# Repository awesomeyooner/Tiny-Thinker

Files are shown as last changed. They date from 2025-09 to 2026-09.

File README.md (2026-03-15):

# Tiny-Thinker
Barebones STM32 board I made to learn PCB design. I took inspiration from [this tutorial](https://www.youtube.com/watch?v=aVUqaB0IMh4) as well as many other videos from PhilsLab, Robert Feranec, and many more!

## Resources

Instead of putting them here, I've put all my notes in this [repo!](https://github.com/awesomeyooner/KiCAD-Library/blob/main/docs/notes/Getting-Started.md)

I hope they're useful!

## Features

This is a 4-Layer PCB centered around the **STM32F446RCT6** (same as STM32F446RET6 but with less flash) with the following stackup:

- **L1** - SIGNAL (with GND Pour)
- **L2** - GND Plane
- **L3** - GND Plane
- **L4** - 3.3V PWR Plane + SIGNAL

Implemented Features:
- USB C FS (Device only)
- 5V Power Multiplexing (5V from USB + 5V from external source)
- User-toggleable LED
- PWR LED
- 2 2x20 Header pins for stackable expansion boards

This board breaks out the following:
- SPI1 and SPI2 (with CS)
- I2C1
- CAN1 (No Transciever)
- SWDIO
- USB_FS
- 8 x TIM Channels
- 4 x ADC Channels
- 4 x GPIO

## Pictures

### Schematic
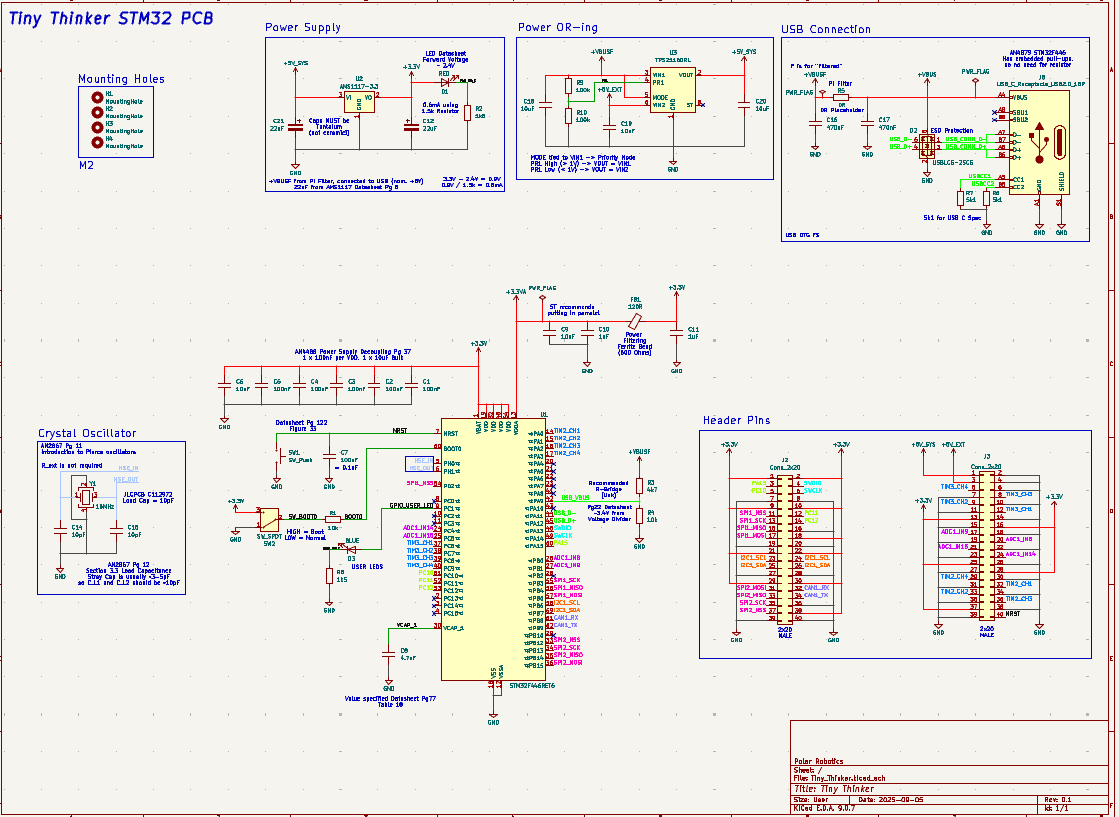
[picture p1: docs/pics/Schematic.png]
Schematic


### Layout and Routing
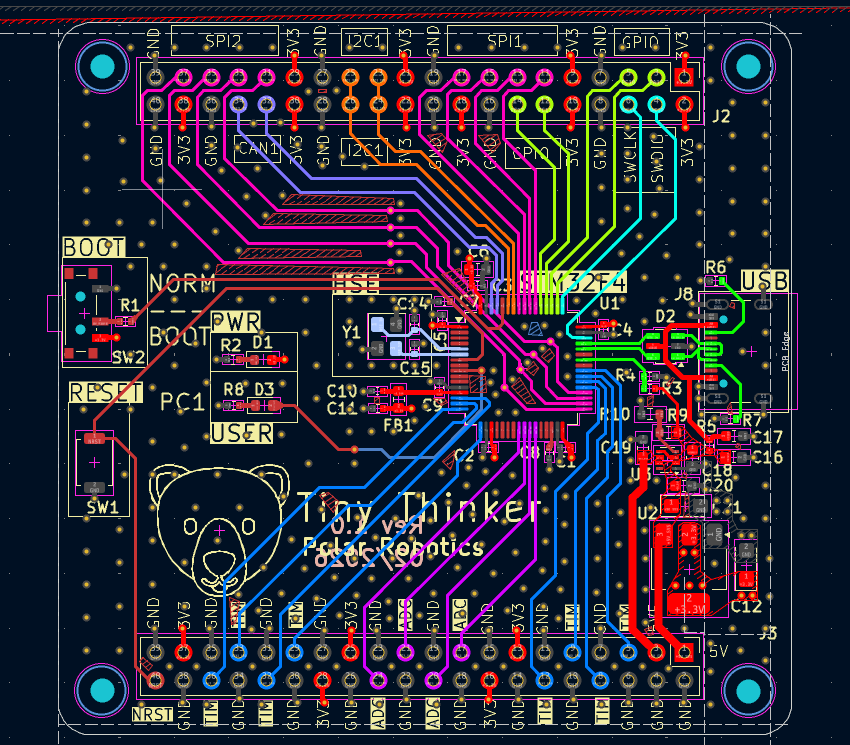
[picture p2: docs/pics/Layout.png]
Layout


### CAD
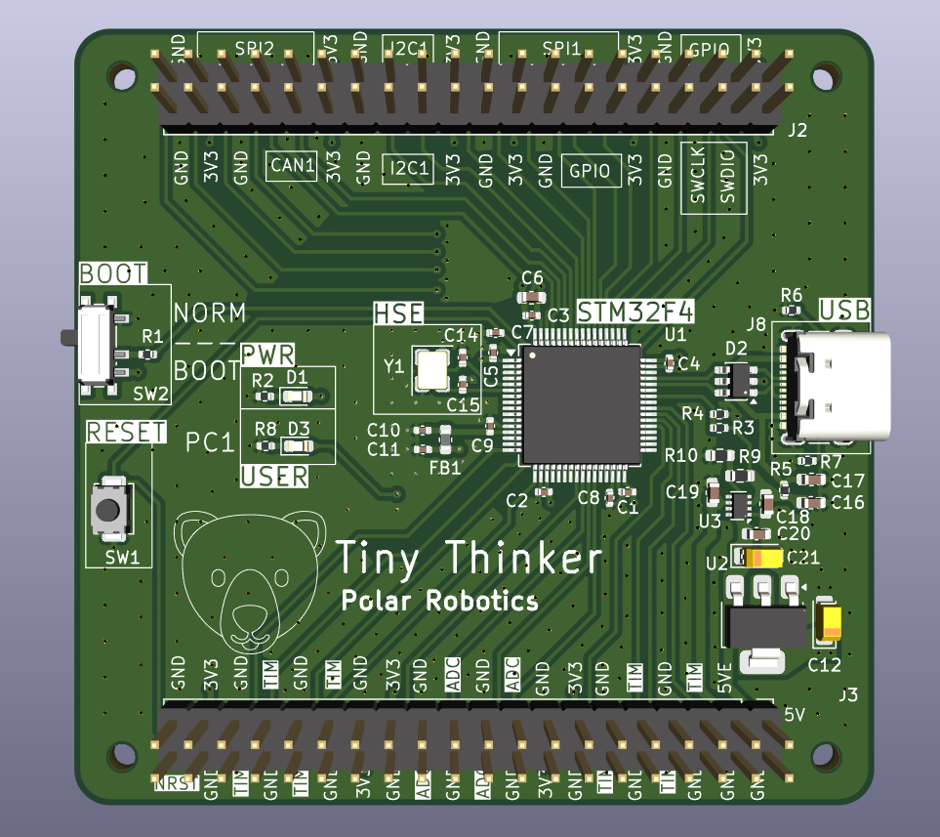
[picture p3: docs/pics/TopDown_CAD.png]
TopDown_CAD


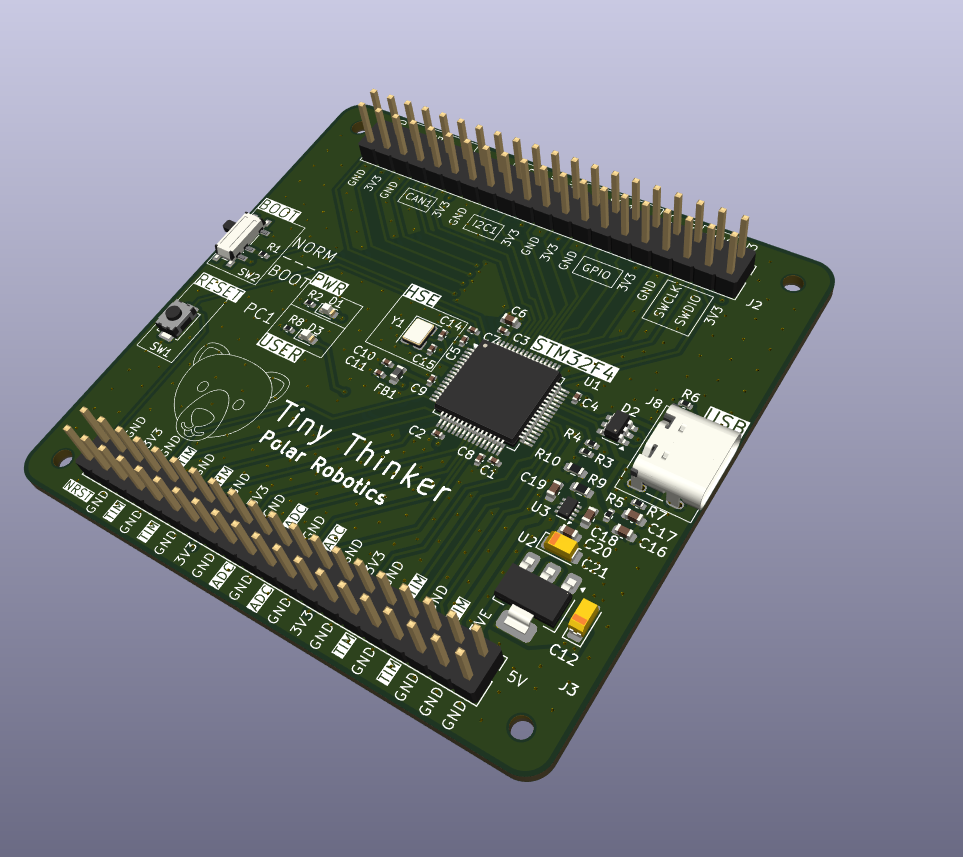
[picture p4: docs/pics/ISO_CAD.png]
ISO_CAD


### Assembled Product
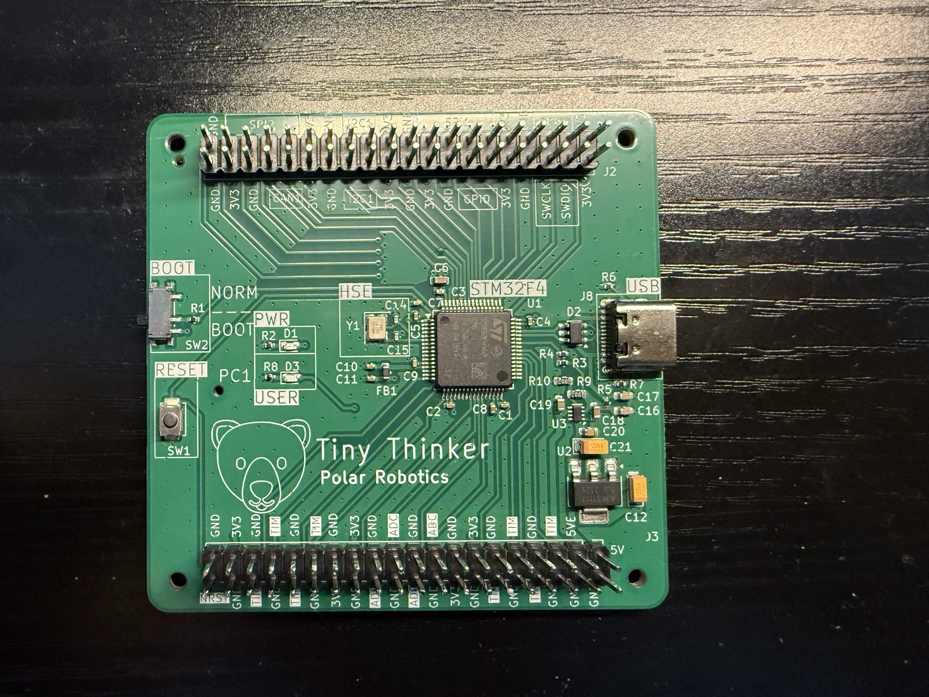
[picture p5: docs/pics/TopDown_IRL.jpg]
TopDown_IRL


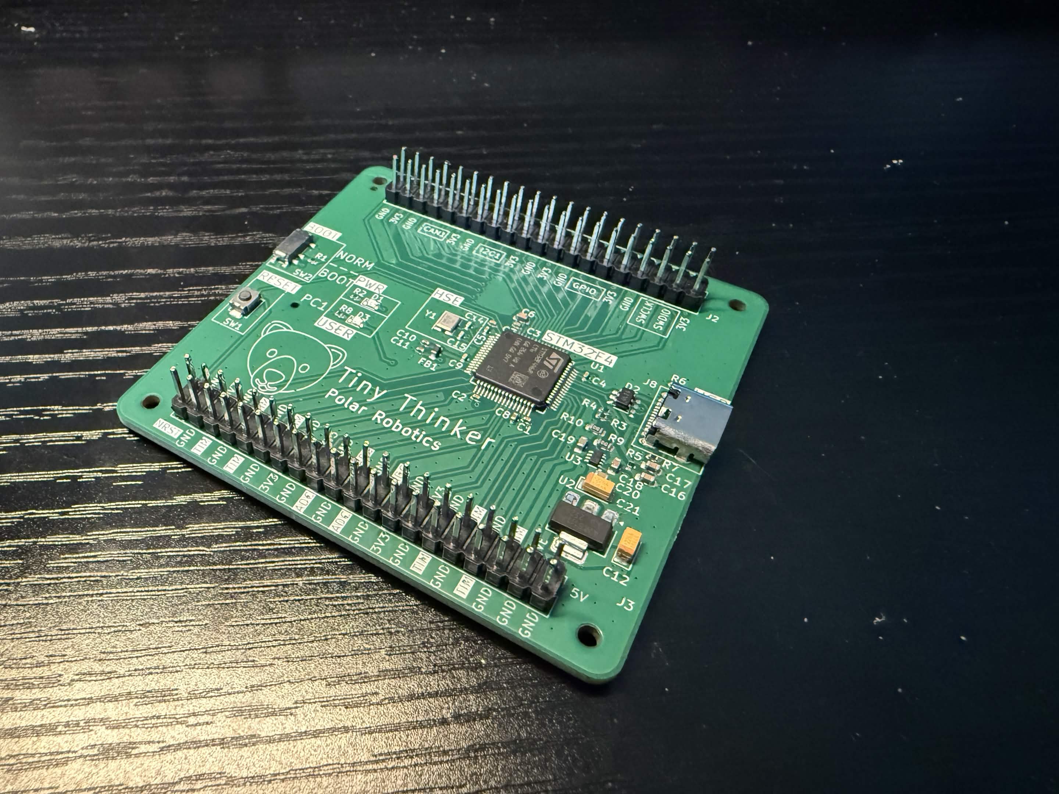
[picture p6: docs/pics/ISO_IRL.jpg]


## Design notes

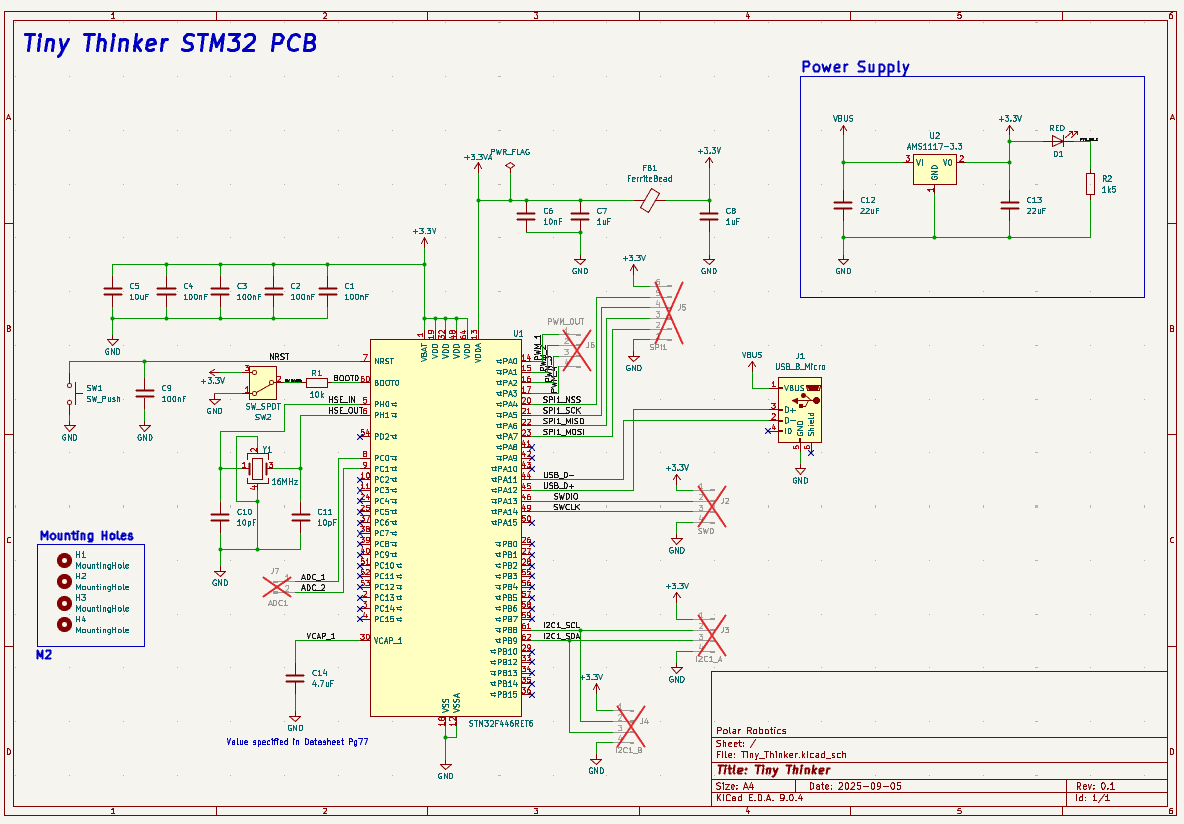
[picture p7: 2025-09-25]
docs/Schematic.png

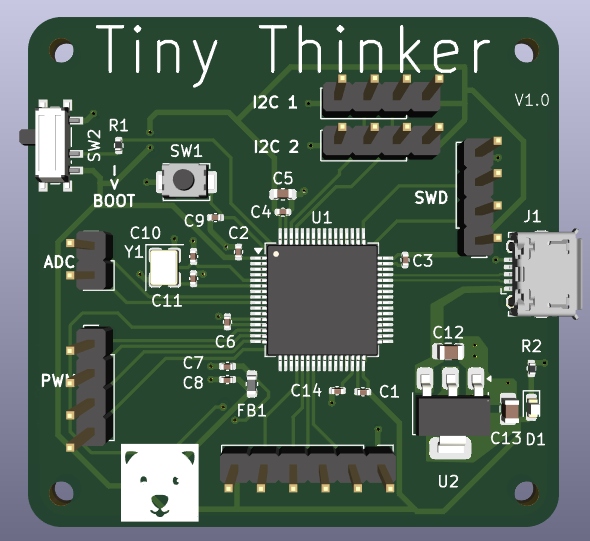
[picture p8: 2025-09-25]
docs/CAD.png

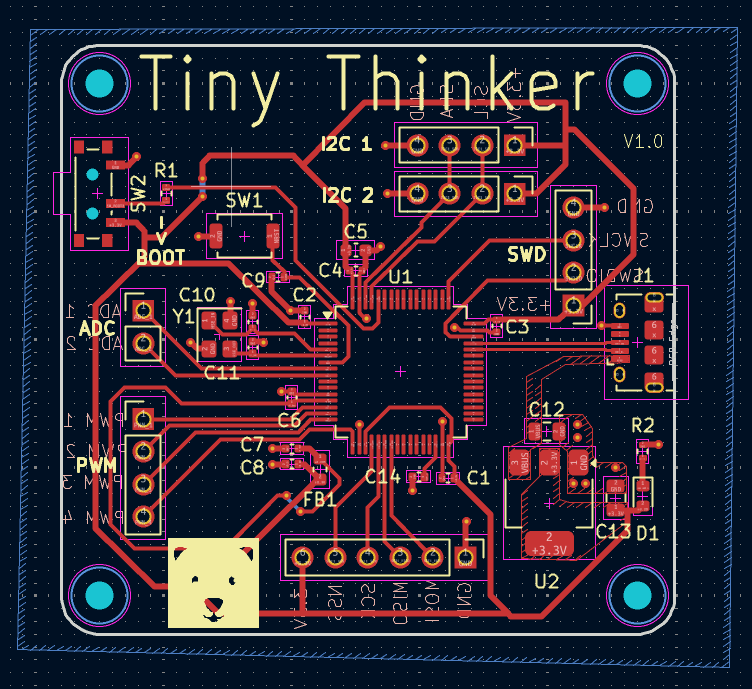
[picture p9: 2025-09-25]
docs/Routing.png

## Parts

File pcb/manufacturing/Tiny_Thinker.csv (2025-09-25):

Comment | Designator | Footprint | JLCPCB Part # | Qty | DNP
100nF | C1,C2,C3,C4,C9 | Capacitor_SMD:C_0402_1005Metric | C1525 | 5
10uF | C5 | Capacitor_SMD:C_0603_1608Metric | C1691 | 1
10nF | C6 | Capacitor_SMD:C_0402_1005Metric | C1524 | 1
1uF | C7,C8 | Capacitor_SMD:C_0402_1005Metric | C14445 | 2
10pF | C10,C11 | Capacitor_SMD:C_0402_1005Metric | C1545 | 2
22uF | C12,C13 | Capacitor_SMD:C_0805_2012Metric | C5674 | 2
4.7uF | C14 | Capacitor_SMD:C_0402_1005Metric | C23733 | 1
RED | D1 | LED_SMD:LED_0603_1608Metric | C2286 | 1
FerriteBead | FB1 | Inductor_SMD:L_0603_1608Metric | C1002 | 1
USB_B_Micro | J1 | Connector_USB:USB_Micro-B_Amphenol_10118194_Horizontal | C132563 | 1
10k | R1 | Resistor_SMD:R_0402_1005Metric | C25531 | 1
1k5 | R2 | Resistor_SMD:R_0402_1005Metric | C25867 | 1
SW_Push | SW1 | Button_Switch_SMD:SW_SPST_TS-1088-xR020 | C720477 | 1
SW_SPDT | SW2 | Button_Switch_SMD:SW_SPDT_PCM12 | C431541 | 1
STM32F446RET6 | U1 | Package_QFP:LQFP-64_10x10mm_P0.5mm | C69336 | 1
AMS1117-3.3 | U2 | Package_TO_SOT_SMD:SOT-223-3_TabPin2 | C6186 | 1
16MHz | Y1 | Crystal:Crystal_SMD_3225-4Pin_3.2x2.5mm | C112972 | 1

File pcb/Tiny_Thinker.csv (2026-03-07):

Comment | Designator | Footprint | JLCPCB Part # | Qty
100nF | C1,C2,C3,C4,C5,C7 | Capacitor_SMD:C_0402_1005Metric | C1525 | 6
10uF | C6,C18,C19,C20 | Capacitor_SMD:C_0603_1608Metric | C19702 | 4
4.7uF | C8 | Capacitor_SMD:C_0402_1005Metric | C23733 | 1
10nF | C9 | Capacitor_SMD:C_0402_1005Metric | C15195 | 1
1uF | C10,C11 | Capacitor_SMD:C_0402_1005Metric | C52923 | 2
22uF | C12,C21 | Capacitor_Tantalum_SMD:CP_EIA-3216-18_Kemet-A | C11366 | 2
10pF | C14,C15 | Capacitor_SMD:C_0402_1005Metric | C32949 | 2
470nF | C16,C17 | Capacitor_SMD:C_0603_1608Metric | C1623 | 2
RED | D1 | LED_SMD:LED_0603_1608Metric | C2286 | 1
USBLC6-2SC6 | D2 | Package_TO_SOT_SMD:SOT-23-6 | C7519 | 1
BLUE | D3 | LED_SMD:LED_0603_1608Metric | C2288 | 1
120R | FB1 | Inductor_SMD:L_0603_1608Metric | C1002 | 1
Conn_2x20 | J2,J3 | Connector_PinHeader_2.54mm:PinHeader_2x20_P2.54mm_Vertical | C50980 | 2
USB_C_Receptacle_USB2.0_16P | J8 | Connector_USB:USB_C_Receptacle_GCT_USB4105-xx-A_16P_TopMnt_Horizontal | C2765186 | 1
10k | R1,R4 | Resistor_SMD:R_0402_1005Metric | C25744 | 2
1k5 | R2,R8 | Resistor_SMD:R_0402_1005Metric | C25867 | 2
4k7 | R3 | Resistor_SMD:R_0402_1005Metric | C25900 | 1
0R | R5 | Resistor_SMD:R_0402_1005Metric | C17168 | 1
5k1 | R6,R7 | Resistor_SMD:R_0402_1005Metric | C25905 | 2
100k | R9,R10 | Resistor_SMD:R_0603_1608Metric | C25803 | 2
SW_Push | SW1 | Button_Switch_SMD:SW_SPST_TS-1088-xR020 | C720477 | 1
SW_SPDT | SW2 | Button_Switch_SMD:SW_SPDT_PCM12 | C431541 | 1
STM32F446RET6 | U1 | Package_QFP:LQFP-64_10x10mm_P0.5mm | C915971 | 1
AMS1117-3.3 | U2 | Package_TO_SOT_SMD:SOT-223-3_TabPin2 | C6186 | 1
TPS2116DRL | U3 | Package_TO_SOT_SMD:SOT-583-8 | C3235557 | 1
16MHz | Y1 | Crystal:Crystal_SMD_3225-4Pin_3.2x2.5mm | C112972 | 1

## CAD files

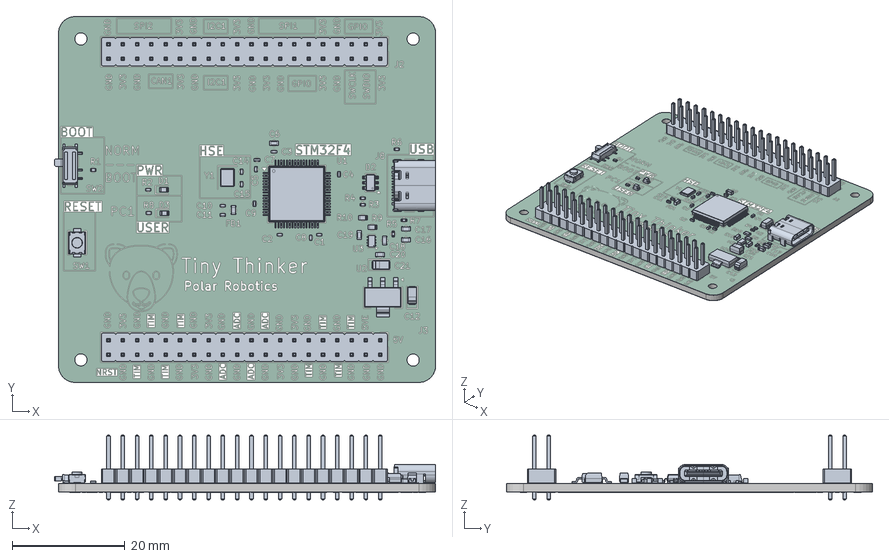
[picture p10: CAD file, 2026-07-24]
pcb/Tiny_Thinker (complex).step
67.7 x 65.0 x 11.5 mm
C_0402_1005Metric x 12
C_0603_1608Metric x 6
LED_0603_1608Metric x 2
SOT-23-6
R_0402_1005Metric x 8
PinHeader_2x20_P2.54mm_Vertical x 2
Crystal_SMD_3225-4Pin_3.2x2.5mm
CP_EIA-3216-18_Kemet-A x 2
SW_SPST_TS-1088-xR020
L_0603_1608Metric
R_0603_1608Metric x 2
LQFP-64_10x10mm_P0.5mm
SOT-223
SW_SPDT_PCM12
USB_C_Receptacle_GCT_USB4105-xx-A_16P_TopMnt_Horizontal
SOT-583-8
Tiny_Thinker_copper
Tiny_Thinker_via
Tiny_Thinker_silkscreen x 2
Tiny_Thinker_soldermask x 2
Tiny_Thinker_PCB

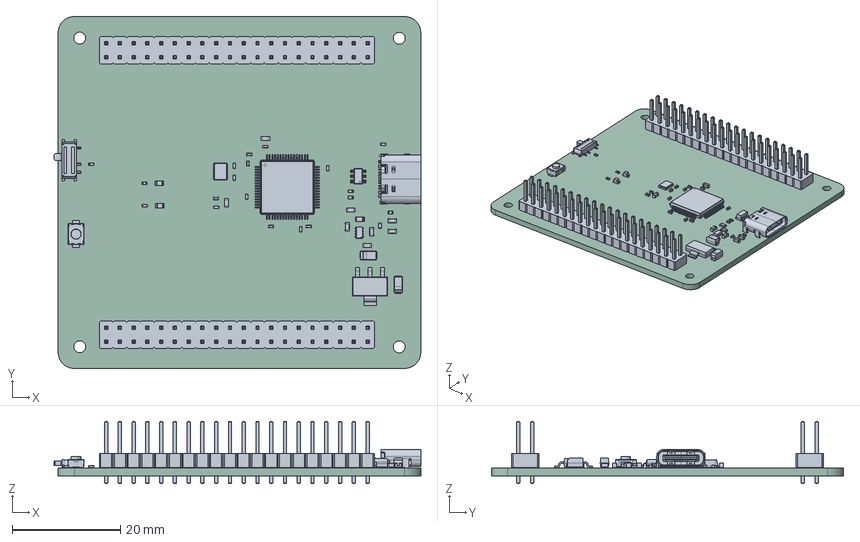
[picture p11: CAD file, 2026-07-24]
pcb/Tiny_Thinker.step
67.7 x 65.0 x 11.5 mm
C_0402_1005Metric x 12
C_0603_1608Metric x 6
LED_0603_1608Metric x 2
SOT-23-6
R_0402_1005Metric x 8
PinHeader_2x20_P2.54mm_Vertical x 2
Crystal_SMD_3225-4Pin_3.2x2.5mm
CP_EIA-3216-18_Kemet-A x 2
SW_SPST_TS-1088-xR020
L_0603_1608Metric
R_0603_1608Metric x 2
LQFP-64_10x10mm_P0.5mm
SOT-223
SW_SPDT_PCM12
USB_C_Receptacle_GCT_USB4105-xx-A_16P_TopMnt_Horizontal
SOT-583-8
Tiny_Thinker_PCB

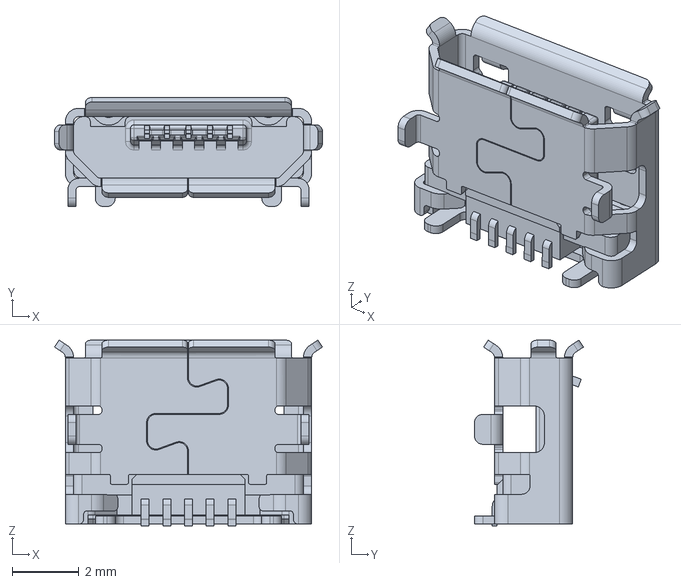
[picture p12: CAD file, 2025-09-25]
pcb/10118194-0001lf.stp
8.05 x 3.27 x 5.58 mm

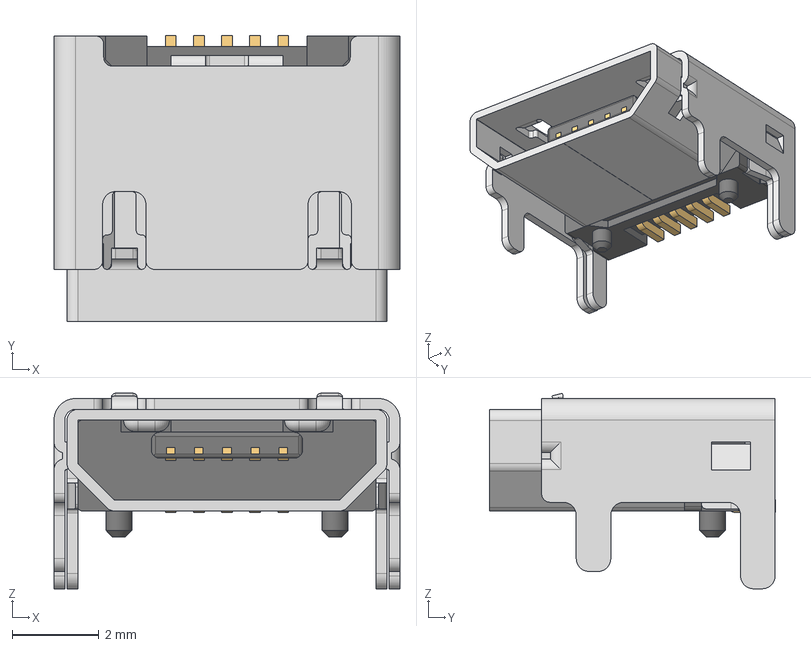
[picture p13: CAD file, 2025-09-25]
pcb/629105150521 (rev1).stp
8.00 x 6.60 x 4.52 mm
629105150521_Housing
629105150521_Pin1 x 4
629105150521_Pin2
629105150521_Shielding2
629105150521_Shielding

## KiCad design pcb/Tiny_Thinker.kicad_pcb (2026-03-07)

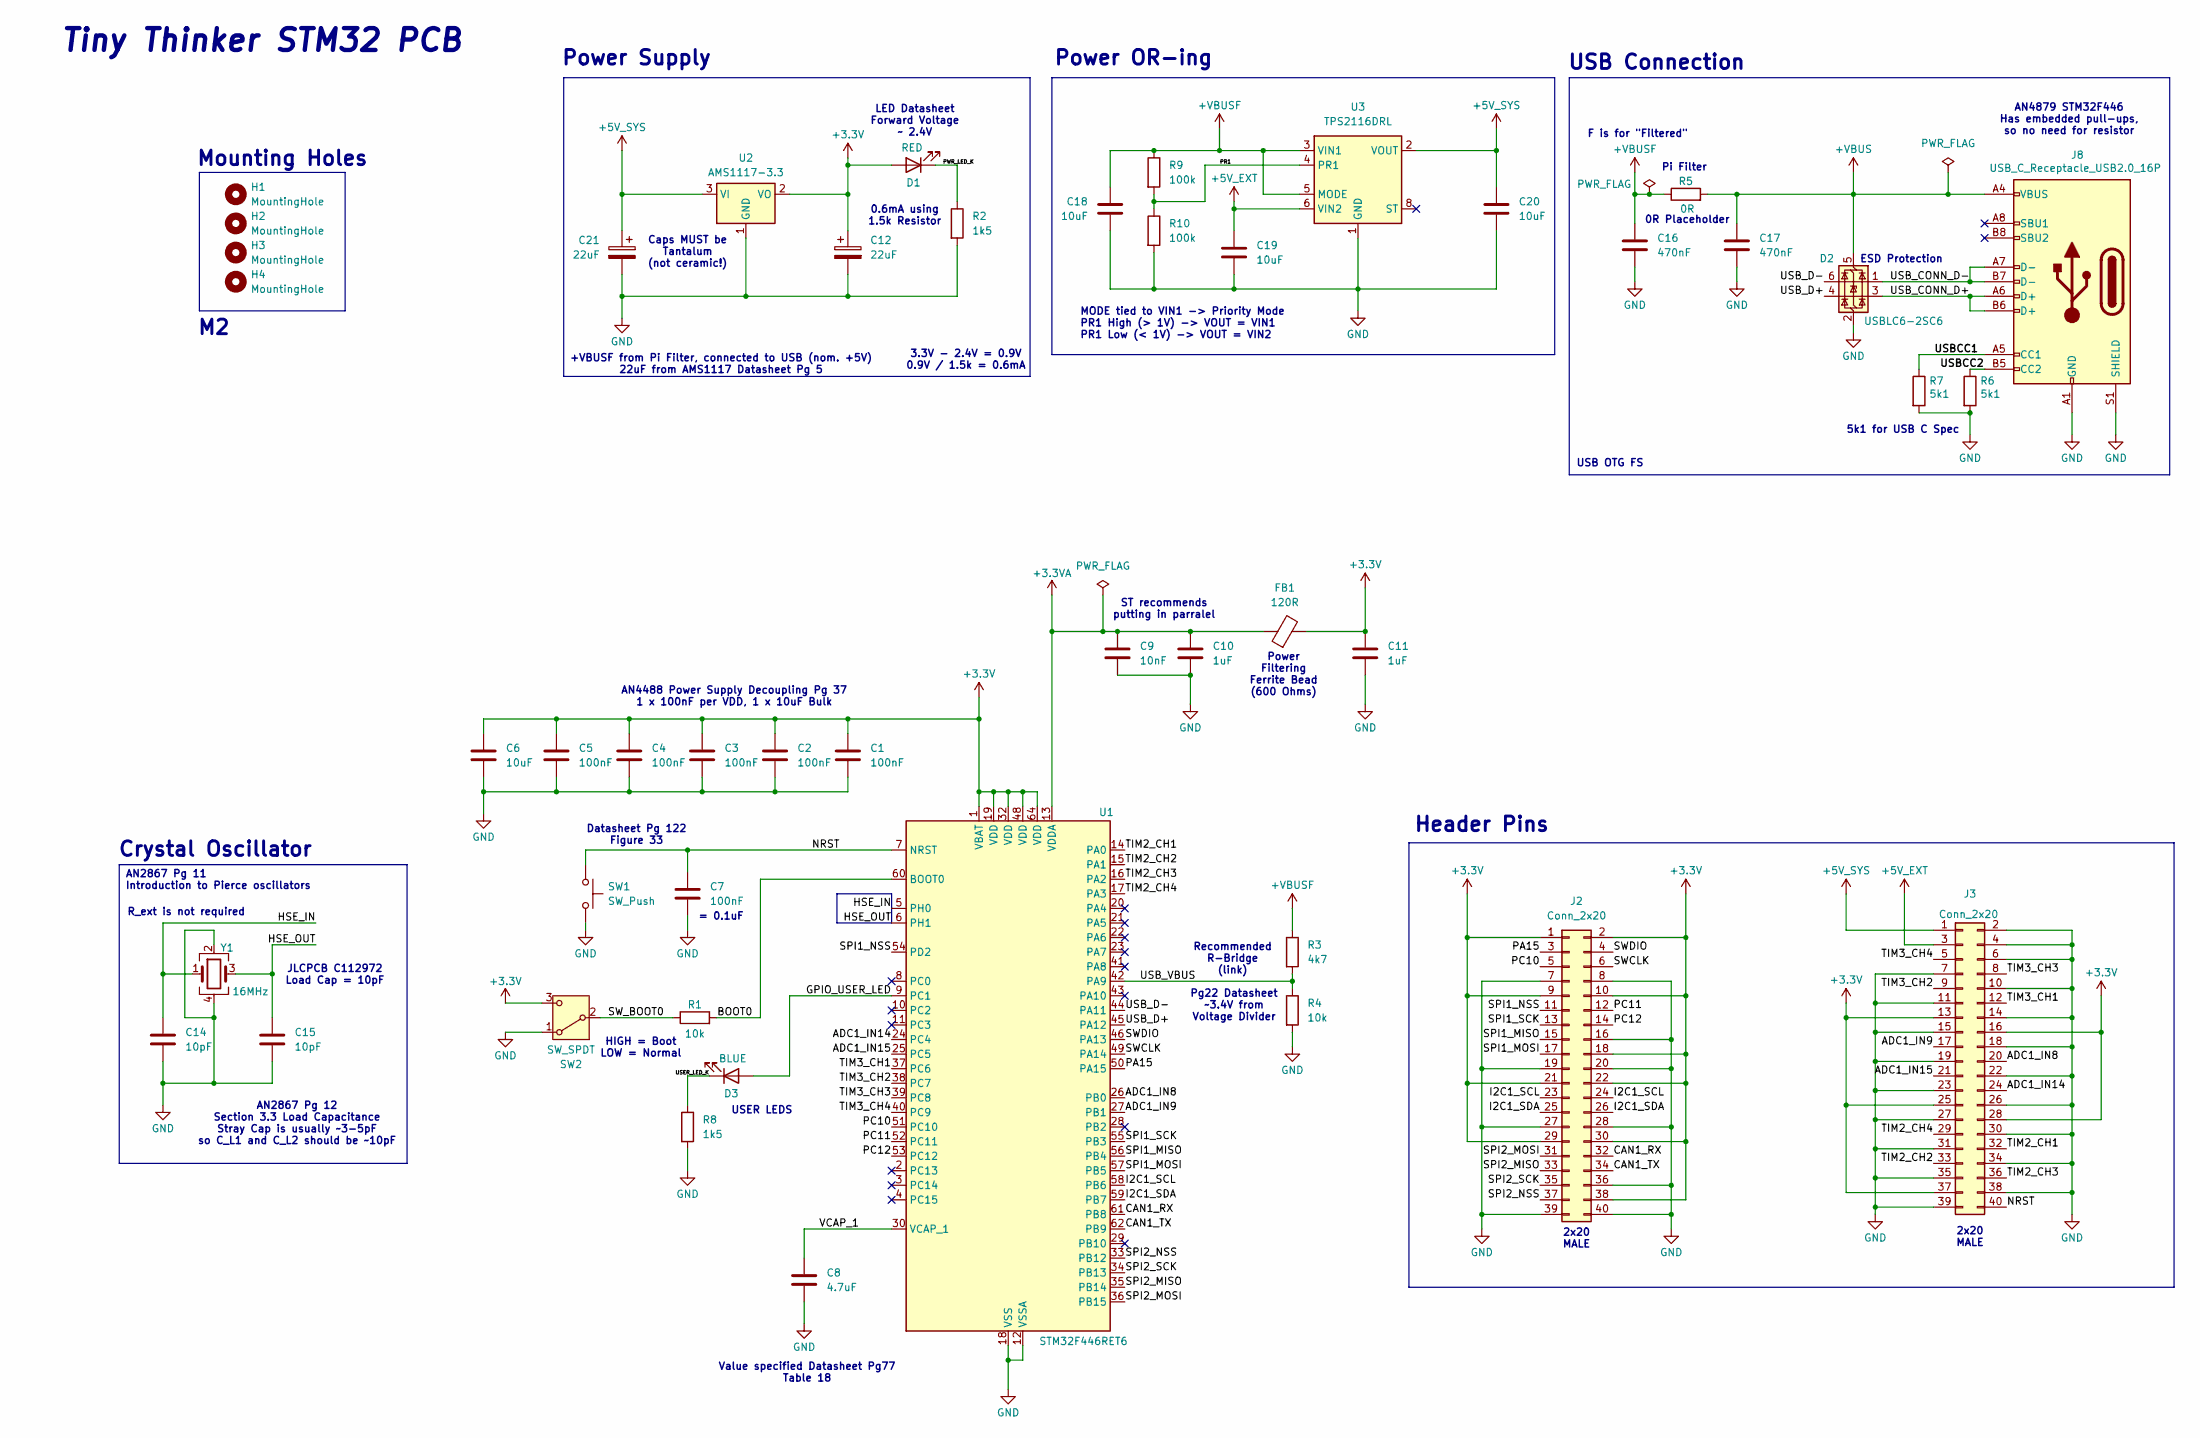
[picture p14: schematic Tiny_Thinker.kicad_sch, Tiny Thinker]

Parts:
C1, C2, C3, C4, C5, C7: 100nF; C_0402_1005Metric; JLCPCB Part # C1525
C6, C18, C19, C20: 10uF; C_0603_1608Metric; JLCPCB Part # C19702
C8: 4.7uF; C_0402_1005Metric; JLCPCB Part # C23733
C9: 10nF; C_0402_1005Metric; JLCPCB Part # C15195
C10, C11: 1uF; C_0402_1005Metric; JLCPCB Part # C52923
C12, C21: 22uF; CP_EIA-3216-18_Kemet-A; JLCPCB Part # C11366
C14, C15: 10pF; C_0402_1005Metric; JLCPCB Part # C32949
C16, C17: 470nF; C_0603_1608Metric; JLCPCB Part # C1623
D1: RED; LED_0603_1608Metric; JLCPCB Part # C2286
D2: USBLC6-2SC6; SOT-23-6; JLCPCB Part # C7519
D3: BLUE; LED_0603_1608Metric; JLCPCB Part # C2288
FB1: 120R; L_0603_1608Metric; JLCPCB Part # C1002
H1, H2, H3, H4: MountingHole; MountingHole_2.2mm_M2
J2, J3: Conn_2x20; PinHeader_2x20_P2.54mm_Vertical; JLCPCB Part # C50980
J8: USB_C_Receptacle_USB2.0_16P; USB_C_Receptacle_GCT_USB4105-xx-A_16P_TopMnt_Horizontal; JLCPCB Part # C2765186
R1, R4: 10k; R_0402_1005Metric; JLCPCB Part # C25744
R2, R8: 1k5; R_0402_1005Metric; JLCPCB Part # C25867
R3: 4k7; R_0402_1005Metric; JLCPCB Part # C25900
R5: 0R; R_0402_1005Metric; JLCPCB Part # C17168
R6, R7: 5k1; R_0402_1005Metric; JLCPCB Part # C25905
R9, R10: 100k; R_0603_1608Metric; JLCPCB Part # C25803
SW1: SW_Push; SW_SPST_TS-1088-xR020; JLCPCB Part # C720477
SW2: SW_SPDT; SW_SPDT_PCM12; JLCPCB Part # C431541
U1: STM32F446RET6; LQFP-64_10x10mm_P0.5mm; JLCPCB Part # C915971
U2: AMS1117-3.3; SOT-223-3_TabPin2; JLCPCB Part # C6186
U3: TPS2116DRL; SOT-583-8; JLCPCB Part # C3235557
Y1: 16MHz; Crystal_SMD_3225-4Pin_3.2x2.5mm; JLCPCB Part # C112972

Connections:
+3.3V: C1.1, C2.1, C3.1, C4.1, C5.1, C6.1, C11.1, C12.1, D1.2 (A), FB1.2, J2.1, J2.2, J2.9, J2.10, J2.18, J2.21, J2.22, J2.29, J2.30, J2.38, J3.13, J3.16, J3.25, J3.28, J3.37, SW2.3 (C), U1.1 (VBAT), U1.19 (VDD), U1.32 (VDD), U1.48 (VDD), U1.64 (VDD), U2.2 (VO)
+3.3VA: C9.1, C10.1, FB1.1, U1.13 (VDDA)
+5V_EXT: C19.1, J3.3, U3.6 (VIN2)
+5V_SYS: C20.1, C21.1, J3.1, U2.3 (VI), U3.2 (VOUT), U3.7 (VOUT)
+VBUS: C17.1, D2.5 (VBUS), J8.A4 (VBUS), J8.A9 (VBUS), J8.B4 (VBUS), J8.B9 (VBUS), R5.2
+VBUSF: C16.1, C18.1, R3.1, R5.1, R9.1, U3.3 (VIN1), U3.5 (MODE)
/ADC1_IN8: J3.20, U1.26 (PB0)
/ADC1_IN9: J3.17, U1.27 (PB1)
/ADC1_IN14: J3.24, U1.24 (PC4)
/ADC1_IN15: J3.21, U1.25 (PC5)
/BOOT0: R1.2, U1.60 (BOOT0)
/CAN1_RX: J2.32, U1.61 (PB8)
/CAN1_TX: J2.34, U1.62 (PB9)
/GPIO_USER_LED: D3.2 (A), U1.9 (PC1)
/HSE_IN: C14.1, U1.5 (PH0), Y1.1
/HSE_OUT: C15.1, U1.6 (PH1), Y1.3
/I2C1_SCL: J2.23, J2.24, U1.58 (PB6)
/I2C1_SDA: J2.25, J2.26, U1.59 (PB7)
/NRST: C7.1, J3.40, SW1.1, U1.7 (NRST)
/PA15: J2.3, U1.50 (PA15)
/PC10: J2.5, U1.51 (PC10)
/PC11: J2.12, U1.52 (PC11)
/PC12: J2.14, U1.53 (PC12)
/PR1: R9.2, R10.1, U3.4 (PR1)
/PWR_LED_K: D1.1 (K), R2.1
/SPI1_MISO: J2.15, U1.56 (PB4)
/SPI1_MOSI: J2.17, U1.57 (PB5)
/SPI1_NSS: J2.11, U1.54 (PD2)
/SPI1_SCK: J2.13, U1.55 (PB3)
/SPI2_MISO: J2.33, U1.35 (PB14)
/SPI2_MOSI: J2.31, U1.36 (PB15)
/SPI2_NSS: J2.37, U1.33 (PB12)
/SPI2_SCK: J2.35, U1.34 (PB13)
/SWCLK: J2.6, U1.49 (PA14)
/SWDIO: J2.4, U1.46 (PA13)
/SW_BOOT0: R1.1, SW2.2 (B)
/TIM2_CH1: J3.32, U1.14 (PA0)
/TIM2_CH2: J3.33, U1.15 (PA1)
/TIM2_CH3: J3.36, U1.16 (PA2)
/TIM2_CH4: J3.29, U1.17 (PA3)
/TIM3_CH1: J3.12, U1.37 (PC6)
/TIM3_CH2: J3.9, U1.38 (PC7)
/TIM3_CH3: J3.8, U1.39 (PC8)
/TIM3_CH4: J3.5, U1.40 (PC9)
/USBCC1: J8.A5 (CC1), R7.1
/USBCC2: J8.B5 (CC2), R6.1
/USB_CONN_D+: D2.3 (I/O2), J8.A6 (D+), J8.B6 (D+)
/USB_CONN_D-: D2.1 (I/O1), J8.A7 (D-), J8.B7 (D-)
/USB_D+: D2.4 (I/O2), U1.45 (PA12)
/USB_D-: D2.6 (I/O1), U1.44 (PA11)
/USB_VBUS: R3.2, R4.1, U1.42 (PA9)
/USER_LED_K: D3.1 (K), R8.1
/VCAP_1: C8.1, U1.30 (VCAP_1)
GND: C1.2, C2.2, C3.2, C4.2, C5.2, C6.2, C7.2, C8.2, C9.2, C10.2, C11.2, C12.2, C14.2, C15.2, C16.2, C17.2, C18.2, C19.2, C20.2, C21.2, D2.2 (GND), J2.7, J2.8, J2.16, J2.19, J2.20, J2.27, J2.28, J2.36, J2.39, J2.40, J3.2, J3.4, J3.6, J3.7, J3.10, J3.11, J3.14, J3.15, J3.18, J3.19, J3.22, J3.23, J3.26, J3.27, J3.30, J3.31, J3.34, J3.35, J3.38, J3.39, J8.A1 (GND), J8.A12 (GND), J8.B1 (GND), J8.B12 (GND), J8.S1 (SHIELD), R2.2, R4.2, R6.2, R7.2, R8.2, R10.2, SW1.2, SW2.1 (A), U1.12 (VSSA), U1.18 (VSS), U1.31 (VSS), U1.47 (VSS), U1.63 (VSS), U2.1 (GND), U3.1 (GND), Y1.2, Y1.4

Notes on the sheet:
Tiny Thinker STM32 PCB
Mounting Holes
Header Pins
+VBUSF from Pi Filter, connected to USB (nom. +5V) 22uF from AMS1117 Datasheet Pg 5
Pi Filter
Caps MUST be Tantalum (not ceramic!)
Crystal Oscillator
2x20 MALE
AN4488 Power Supply Decoupling Pg 37 1 x 100nF per VDD, 1 x 10uF Bulk
0R Placeholder
Power OR-ing
HIGH = Boot LOW = Normal
ESD Protection
F is for "Filtered"
USB Connection
MODE tied to VIN1 -> Priority Mode PR1 High (> 1V) -> VOUT = VIN1 PR1 Low (< 1V) -> VOUT = VIN2
Power Filtering Ferrite Bead (600 Ohms)
AN4879 STM32F446 Has embedded pull-ups, so no need for resistor
USER LEDS
Value specified Datasheet Pg77 Table 18
= 0.1uF
3.3V - 2.4V = 0.9V 0.9V / 1.5k = 0.6mA
JLCPCB C112972 Load Cap = 10pF
USB OTG FS
AN2867 Pg 11 Introduction to Pierce oscillators
LED Datasheet Forward Voltage ~ 2.4V
0.6mA using 1.5k Resistor
AN2867 Pg 12 Section 3.3 Load Capacitance Stray Cap is usually ~3-5pF so C_L1 and C_L2 should be ~10pF
ST recommends putting in parralel
R_ext is not required
5k1 for USB C Spec
Pg22 Datasheet ~3.4V from Voltage Divider
Power Supply
Recommended R-Bridge (link)
Datasheet Pg 122 Figure 33

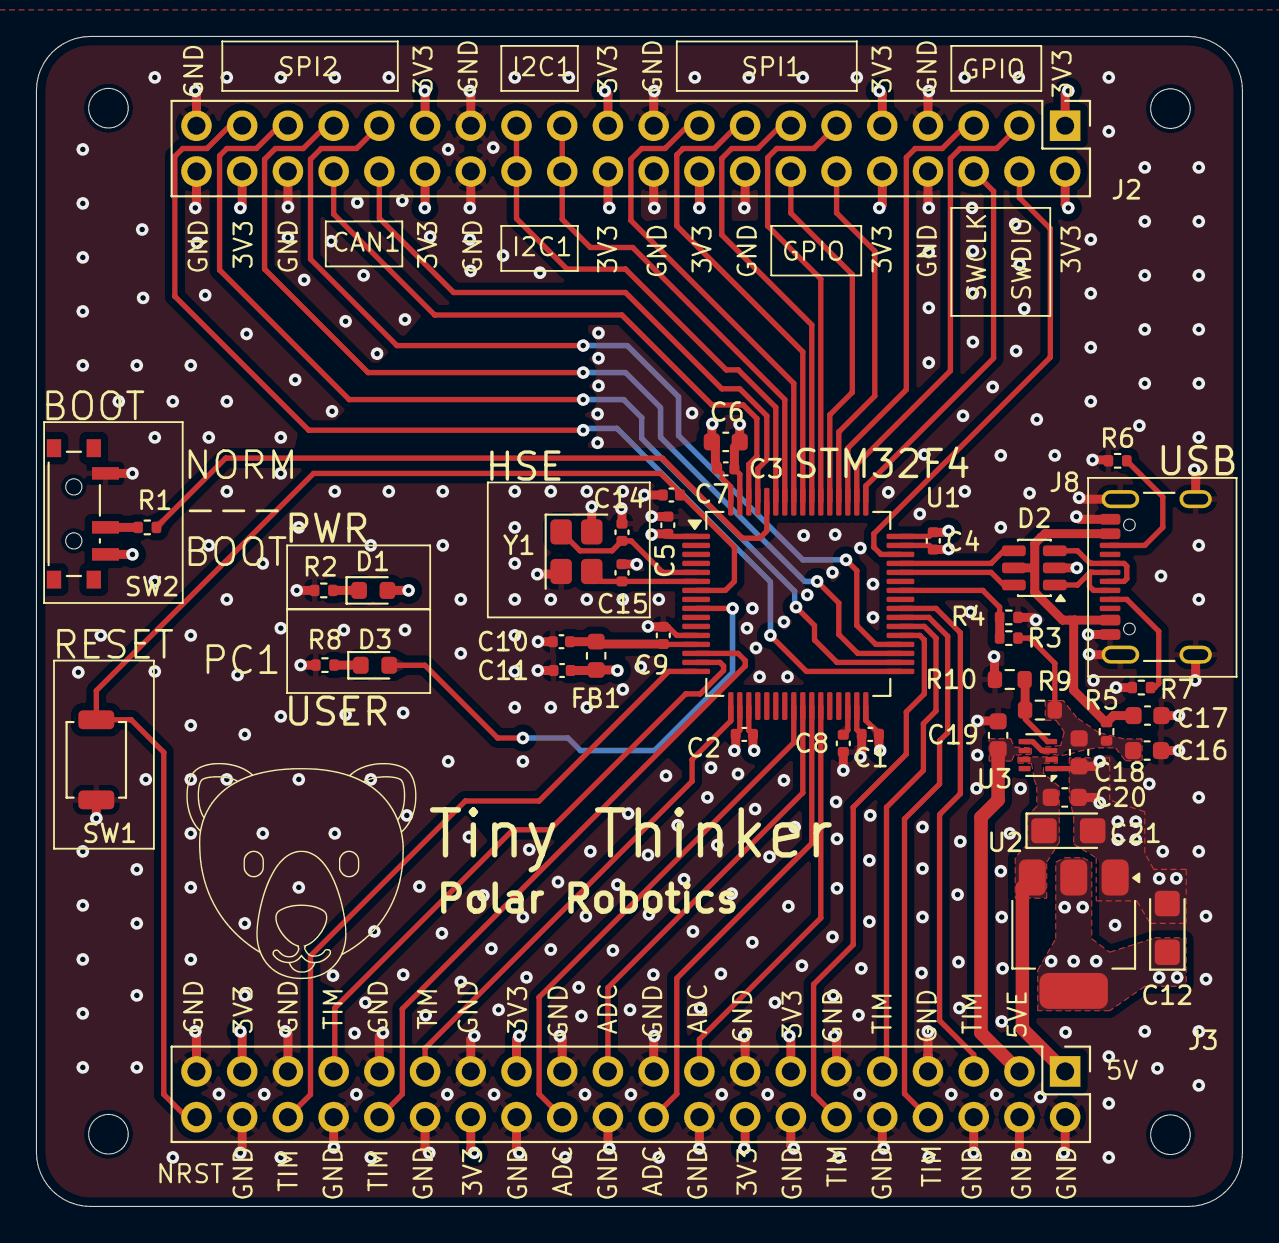
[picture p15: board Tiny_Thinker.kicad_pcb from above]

Board: 4 copper layers, 67.0 x 65.0 mm, 47 parts (0 on the bottom side), 54 nets.

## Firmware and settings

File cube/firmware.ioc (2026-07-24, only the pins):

Mcu.UserName=STM32F446RCTx
PA0-WKUP.Signal=S_TIM2_CH1_ETR
PA1.Signal=S_TIM2_CH2
PA11.Signal=USB_OTG_FS_DM
PA12.Signal=USB_OTG_FS_DP
PA13.Signal=SYS_JTMS-SWDIO
PA14.Signal=SYS_JTCK-SWCLK
PA15.Signal=GPIO_Output
PA2.Signal=S_TIM2_CH3
PA3.Signal=S_TIM2_CH4
PA9.Signal=USB_OTG_FS_VBUS
PB0.Signal=ADCx_IN8
PB1.Signal=ADCx_IN9
PB12.Signal=SPI2_NSS
PB13.Signal=SPI2_SCK
PB14.Signal=SPI2_MISO
PB15.Signal=SPI2_MOSI
PB3.Signal=SPI1_SCK
PB4.Signal=SPI1_MISO
PB5.Signal=SPI1_MOSI
PB6.Signal=I2C1_SCL
PB7.Signal=I2C1_SDA
PB8.Signal=CAN1_RX
PB9.Signal=CAN1_TX
PC1.Signal=GPIO_Output
PC10.Signal=GPIO_Output
PC11.Signal=GPIO_Output
PC12.Signal=GPIO_Output
PC4.Signal=ADCx_IN14
PC5.Signal=ADCx_IN15
PC6.Signal=S_TIM8_CH1
PC7.Signal=S_TIM8_CH2
PC8.Signal=S_TIM3_CH3
PC9.Signal=S_TIM3_CH4
PD2.Signal=GPIO_Output
PH0-OSC_IN.Signal=RCC_OSC_IN
PH1-OSC_OUT.Signal=RCC_OSC_OUT

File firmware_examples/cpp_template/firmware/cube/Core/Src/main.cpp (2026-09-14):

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
/* Includes ------------------------------------------------------------------*/
#include "main.h"
#include "usb_device.h"
#include "gpio.h"

/* USER CODE BEGIN Includes */
#include "core.hpp"
/* USER CODE END Includes */


#ifdef __cplusplus
extern "C" {
#endif

void SystemClock_Config(void);

#ifdef __cplusplus
}
#endif
/**
  * @brief  The application entry point.
  * @retval int
  */
int main(void)
{

  /* MCU Configuration--------------------------------------------------------*/

  /* Reset of all peripherals, Initializes the Flash interface and the Systick. */
  HAL_Init();

  /* Configure the system clock */
  SystemClock_Config();

  /* Initialize all configured peripherals */
  MX_GPIO_Init();
  MX_USB_DEVICE_Init();
  /* USER CODE BEGIN 2 */
    init();
  /* USER CODE END 2 */

  /* Infinite loop */
  /* USER CODE BEGIN WHILE */
  while (1)
  {
    /* USER CODE END WHILE */
    update();
    /* USER CODE BEGIN 3 */
  }
  /* USER CODE END 3 */
}

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


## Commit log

2025-09-25 added initial project
    [10118194-0001lf.stp, 629105150521 (rev1).stp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]
2025-09-25 removed unused cpl
    [Tiny_Thinker-bottom-pos.csv, Tiny_Thinker-top-pos.csv]
2025-09-27 reorganized project structure
    [10118194-0001lf.stp, 629105150521 (rev1).stp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]
2025-10-04 added 40pin (WIP)
    [Tiny_Thinker.kicad_sch]
2025-10-05 added extra 100nf cap
    [Tiny_Thinker.kicad_pcb, Tiny_Thinker.kicad_sch]
2025-10-13 I honestly forgot what I did
    [Tiny_Thinker.kicad_pcb]
2025-10-14 i dont even know
    [Tiny_Thinker.kicad_pcb]
2026-01-07 added redesign project so I can use the old one as reference
    [10118194-0001lf.stp, 629105150521 (rev1).stp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]
2026-01-07 switched names
    [10118194-0001lf.stp, 629105150521 (rev1).stp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]
2026-01-08 changed pinout
    [Tiny_Thinker.kicad_sch]
2026-01-08 added more comments are made the schematic neater
    [Tiny_Thinker.kicad_sch]
2026-01-08 added USB C with ESD Protection
    [Tiny_Thinker.kicad_sch]
2026-01-08 more comments
    [Tiny_Thinker.kicad_sch]
2026-01-08 Assigned footprints
    [Tiny_Thinker.kicad_sch]
2026-01-08 gave colors to all netclasses
    [Tiny_Thinker.kicad_sch]
2026-01-08 Added JLCPCB capabilities
    [Tiny_Thinker.kicad_pcb, Tiny_Thinker.kicad_sch]
2026-01-08 before I start editting the pcb
2026-01-08 i forgot to add this one
    [Tiny_Thinker.kicad_sch]
2026-01-08 renamed the capacitors to be in order
    [Tiny_Thinker.kicad_sch]
2026-01-23 routed traces, changed 2x16 to 2x20, defined the dimensions
2026-01-23 I forgot to save. The previous message is what this commit is
    [Tiny_Thinker.kicad_pcb, Tiny_Thinker.kicad_sch]
2026-01-23 im not sure what I did
    [Tiny_Thinker.kicad_pcb]
2026-01-24 named USB connectors
    idk why they keep on resetting
    [Tiny_Thinker.kicad_pcb]
2026-01-24 i forgot to save again
    [Tiny_Thinker.kicad_pcb, Tiny_Thinker.kicad_sch]
2026-01-24 added misc pins
    [Tiny_Thinker.kicad_pcb]
2026-01-24 added ground pour to L1
    [Tiny_Thinker.kicad_pcb]
2026-01-24 finished adding vias to header pins (not stitching)
    [Tiny_Thinker.kicad_pcb]
2026-01-24 started adding stitching vias
    [Tiny_Thinker.kicad_pcb]
2026-01-24 added logo
    [Tiny_Thinker.kicad_pcb]
2026-01-24 updated bom / added JLC part #
    [Tiny_Thinker.kicad_pcb, Tiny_Thinker.kicad_sch]
2026-01-24 refreshed bom
    [Tiny_Thinker-B_Cu.gbr, Tiny_Thinker-B_Mask.gbr, Tiny_Thinker-B_Paste.gbr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]
2026-01-28 Revised JLCPCB capabilities
    [Tiny_Thinker.kicad_pcb, Tiny_Thinker.kicad_sch]
2026-01-28 cleaned up routing of USB data lines
    [Tiny_Thinker.kicad_pcb]
2026-01-28 Added more comments
    [Tiny_Thinker.kicad_sch]
2026-01-31 renamed pinout folder to cube (for stm32cubemx)
2026-02-06 renamed USB C net labels
    [Tiny_Thinker.kicad_sch]
2026-02-06 changed header routing to be more spaced out
    [Tiny_Thinker.kicad_pcb]
2026-02-06 Added user led
    [Tiny_Thinker.kicad_pcb, Tiny_Thinker.kicad_sch]
2026-02-06 cleaned up routing
    [Tiny_Thinker.kicad_pcb, Tiny_Thinker.kicad_sch]
2026-02-06 changed dimensions to be whole numbers
    [Tiny_Thinker.kicad_pcb]
2026-02-06 added and routed TPS2116 Power OR-ing IC
    [Tiny_Thinker.kicad_pcb, Tiny_Thinker.kicad_sch]
2026-02-06 added copper pour for VBUSF
    [Tiny_Thinker.kicad_pcb]
2026-02-06 broke out +5V external supply for expandability
    [Tiny_Thinker.kicad_pcb, Tiny_Thinker.kicad_sch]
2026-02-06 DRC cehck
    [Tiny_Thinker.kicad_pcb]
2026-02-12 changed 10k Ohm resistor JLCPCB part and removed fiducial markers (jlc does it for you)
    [Tiny_Thinker-B_Cu.gbr, Tiny_Thinker-B_Mask.gbr, Tiny_Thinker-B_Paste.gbr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]
2026-02-12 rearranged silkscreen
    [Tiny_Thinker.kicad_pcb]
2026-02-17 added stitching vias and cleaned up silkscreen
    [Tiny_Thinker.kicad_pcb, Tiny_Thinker.kicad_sch]
2026-02-17 added more stitching vias
    [Tiny_Thinker.kicad_pcb]
2026-02-17 removed DNP from BOM
    [Tiny_Thinker-B_Cu.gbr, Tiny_Thinker-B_Mask.gbr, Tiny_Thinker-B_Paste.gbr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]
2026-02-20 moved NRST 100nF capacitor closer to pin
    [Tiny_Thinker.kicad_pcb]
2026-02-21 renamed header connectors for BOM and connected NRST to a pin
    [Tiny_Thinker.kicad_pcb, Tiny_Thinker.kicad_sch]
2026-02-21 put knockout text on NRST pin
    [Tiny_Thinker.kicad_pcb]
2026-02-22 Added silkscreen for USER LED
    [Tiny_Thinker.kicad_pcb]
2026-02-22 updated gerbers
    [Tiny_Thinker-B_Cu.gbr, Tiny_Thinker-B_Mask.gbr, Tiny_Thinker-B_Paste.gbr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]
2026-02-25 added more comments to schematic
    [Tiny_Thinker.kicad_sch, Tiny_Thinker.step]
2026-02-25 changed AMS caps to tantalum per spec
    [Tiny_Thinker.kicad_pcb, Tiny_Thinker.kicad_sch]
2026-02-25 comments on TPS2116
    [Tiny_Thinker.kicad_sch]
2026-02-25 added manufacturing files
    [Tiny_Thinker-B_Cu.gbr, Tiny_Thinker-B_Mask.gbr, Tiny_Thinker-B_Paste.gbr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]
2026-02-25 minor ground plane edits
    [Tiny_Thinker.kicad_pcb]
2026-02-25 regenerated manufacturing files
    [Tiny_Thinker-B_Cu.gbr, Tiny_Thinker-B_Mask.gbr, Tiny_Thinker-B_Paste.gbr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]
2026-02-26 updated manufacturing files
    [Tiny_Thinker.csv, Tiny_Thinker.kicad_pcb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]
2026-02-26 minor changes to GND plane
    I hate being paranoid
    [Tiny_Thinker-B_Cu.gbr, Tiny_Thinker-B_Mask.gbr, Tiny_Thinker-B_Paste.gbr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]
2026-04-05 Added STEP Files
    [Tiny_Thinker (complex).step, Tiny_Thinker.step]
2026-07-24 removed the `/old` folder and replaced old .ioc file with correct STM32F446RCT6 ioc file
    [10118194-0001lf.stp, 629105150521 (rev1).stp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]

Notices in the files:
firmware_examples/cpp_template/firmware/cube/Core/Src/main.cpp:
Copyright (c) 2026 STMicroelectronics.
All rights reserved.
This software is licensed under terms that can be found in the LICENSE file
